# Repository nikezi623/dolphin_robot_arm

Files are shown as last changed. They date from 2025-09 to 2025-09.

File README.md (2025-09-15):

# 🐬 Dolphin Robot Arm

> 基于 STM32F103C8T6 + PS2 手柄的 3 自由度桌面海豚机械臂（包含 SW 模型） 

---

## 📷 项目预览

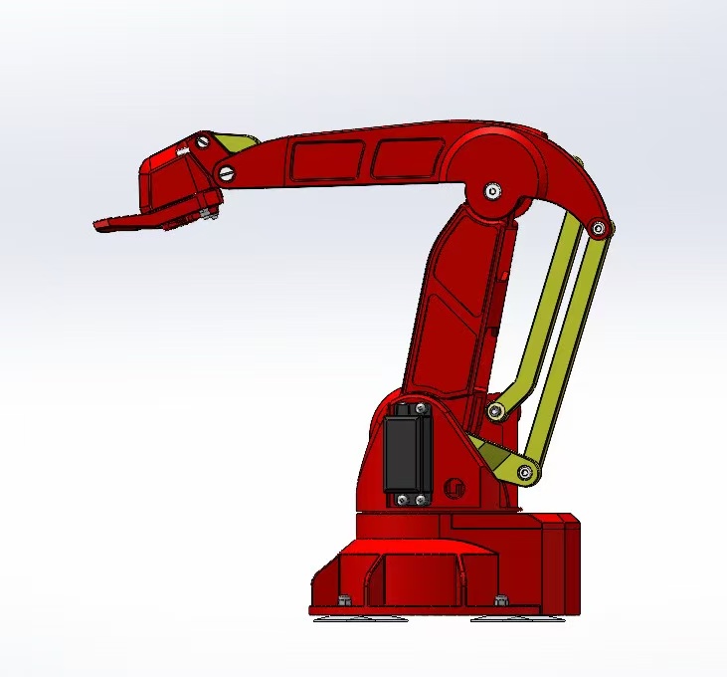
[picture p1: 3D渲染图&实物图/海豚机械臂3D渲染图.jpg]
3D渲染图
<br>
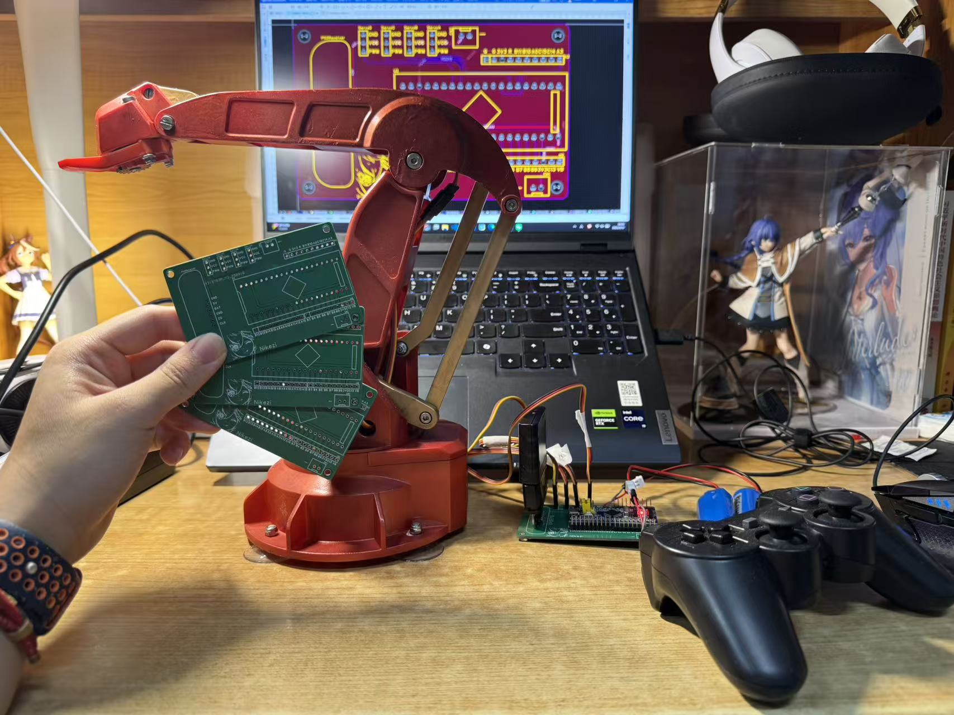
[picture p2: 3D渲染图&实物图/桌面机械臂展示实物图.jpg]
3D渲染图
<br>

[🎥 点击观看演示视频](https://www.bilibili.com/video/BV1tHa8zaEXb/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)

---

## 💻 装配视频<br>
### 视频教程需要付费，作者本人也是跟着视频教程学习的，如无学习建模需求，建议对照本项目的装配体文件自行装配<br>
[🎥 点击跳转装配教程](https://www.bilibili.com/cheese/play/ep34546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)

---

## 原理图<br>
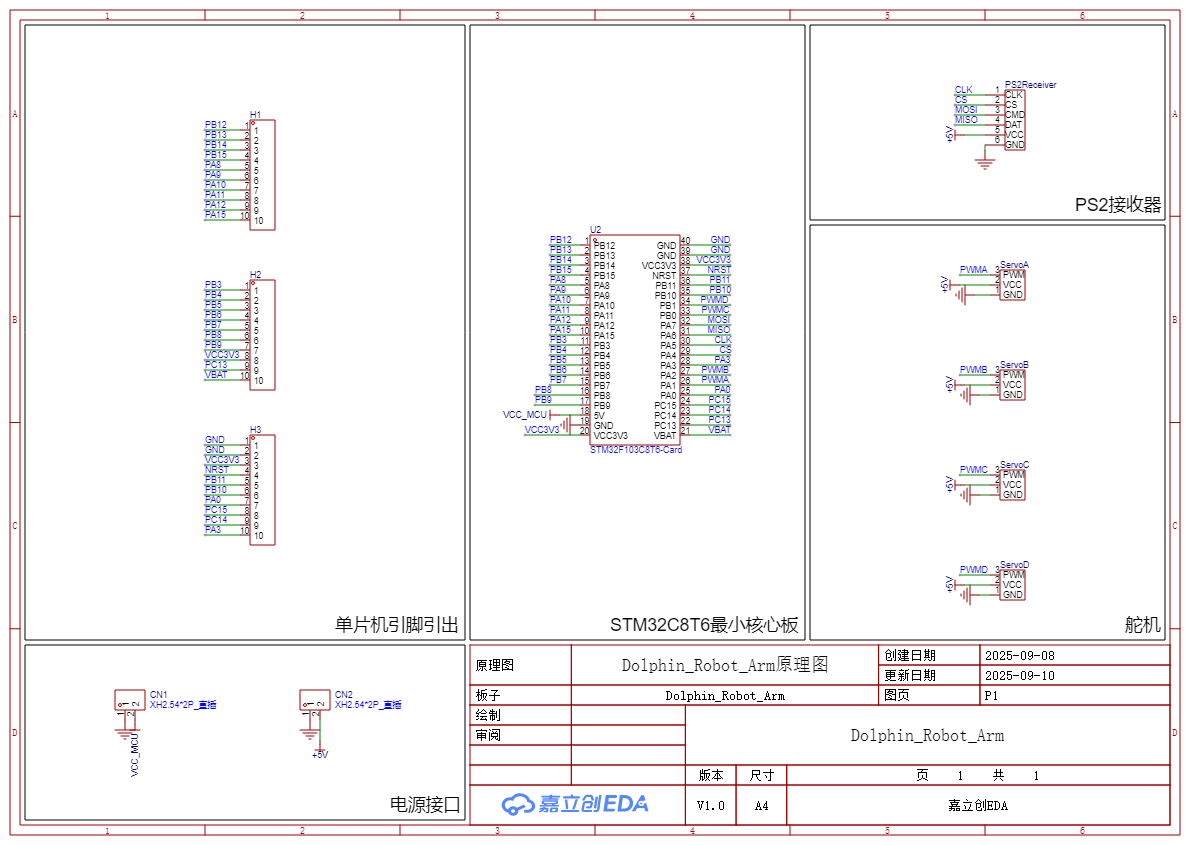
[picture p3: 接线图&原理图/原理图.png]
接线图


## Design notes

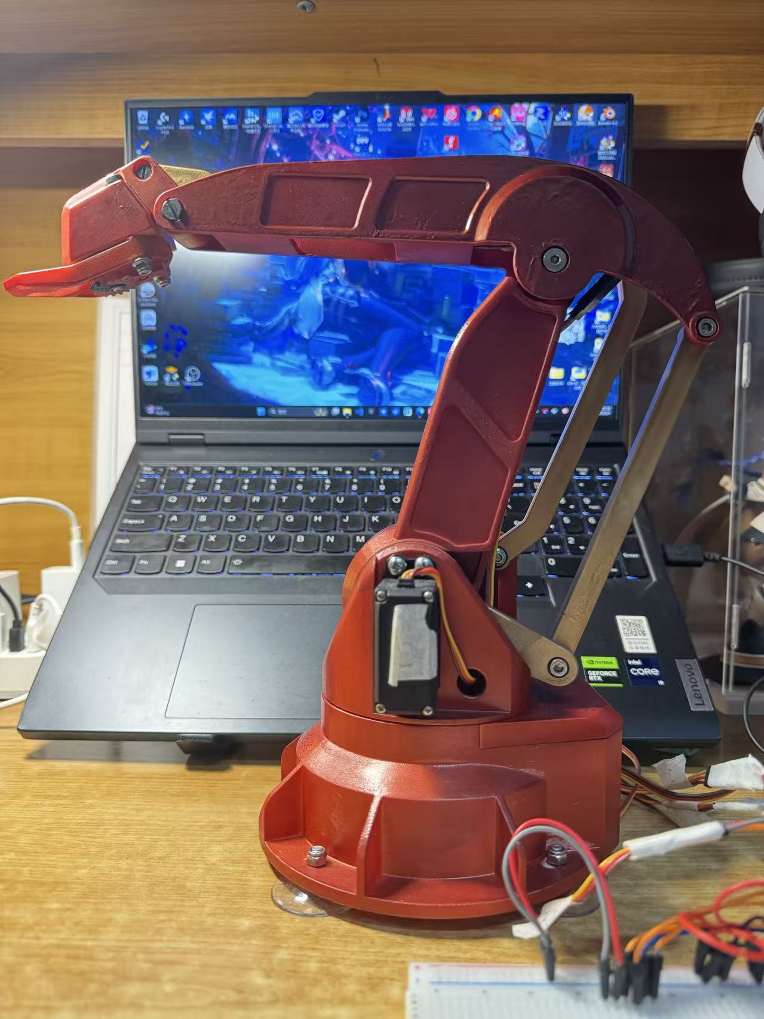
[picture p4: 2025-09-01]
3D渲染图&实物图/海豚机械臂实物图.jpg

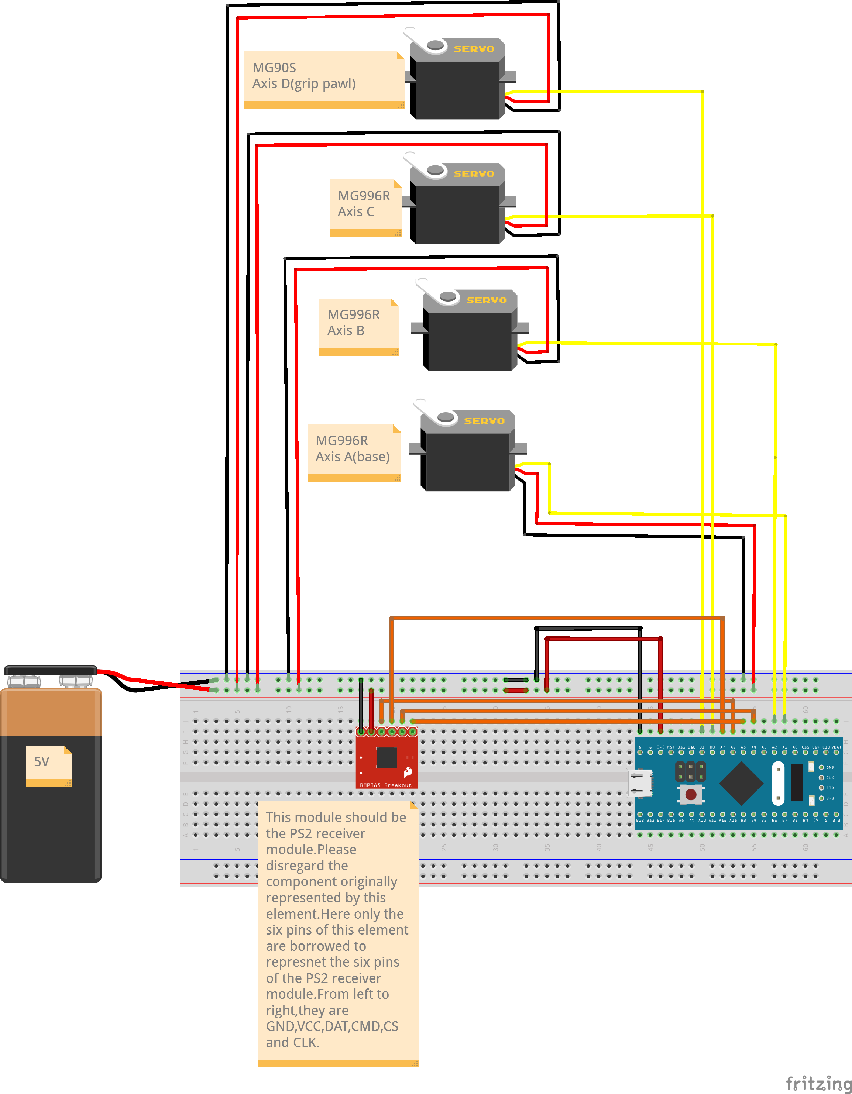
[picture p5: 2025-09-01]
接线图&原理图/接线图-generate_by_fritzing.png

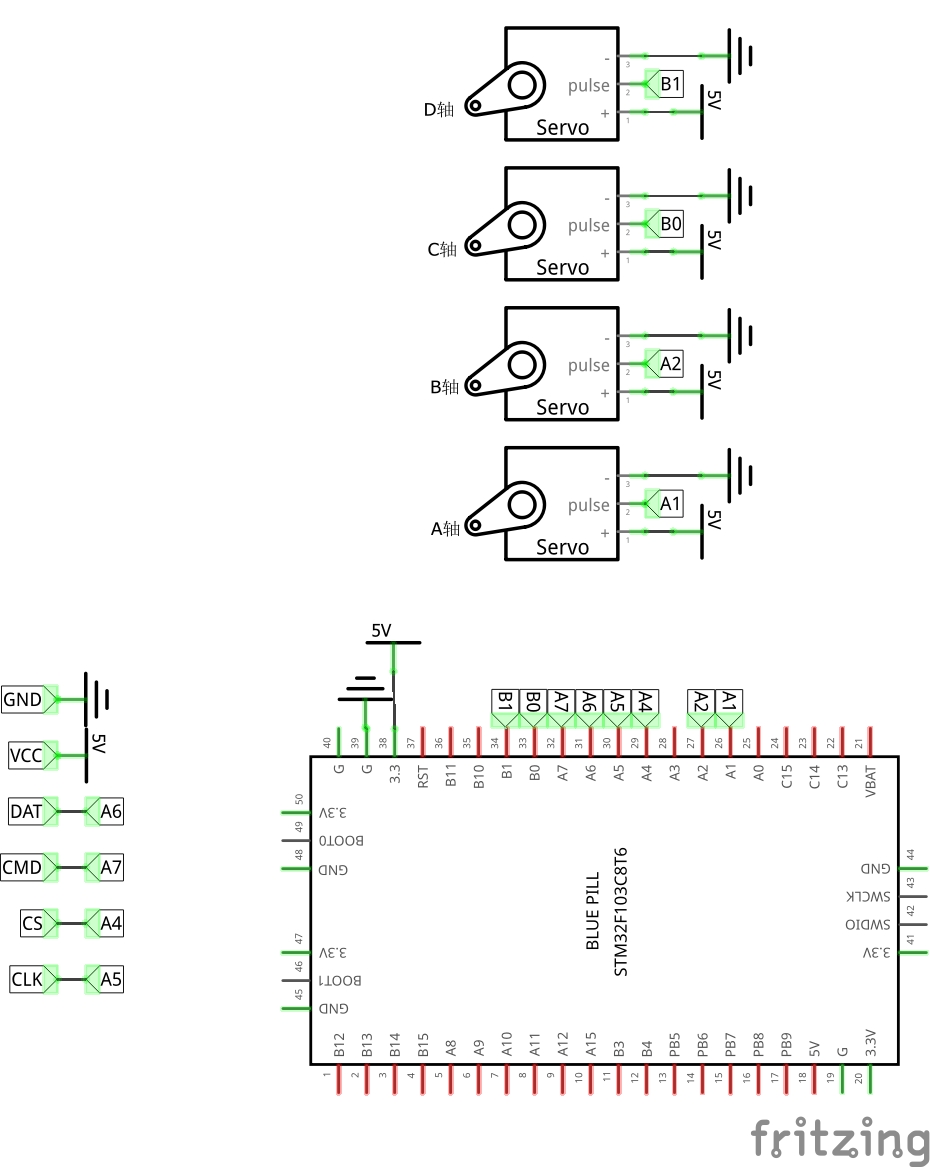
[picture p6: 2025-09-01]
接线图&原理图/原理图-generate_by_fritzing.jpg

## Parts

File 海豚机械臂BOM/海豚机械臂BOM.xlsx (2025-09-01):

海豚机械臂配件表
序号 | 名称 | 链接 | 备注 | 单价 | 数量 | 小计
1 | 标准舵机 | https://detail.tmall.com/item.htm?id=587390473616&_u=lktr7u1ac75&skuId=4166432811194 | MG996 180度 | ￥25.80 | 3 | ￥77.40
2 | 舵机MG90s | https://detail.tmall.com/item.htm?id=587206744069&spm=a1z09.2.0.0.199e2e8d0tGDsQ&_u=lktr7u14a1d | 模拟MG90S 90-180度其他舵机不保证尺寸相同 | ￥16.21 | 1 | ￥16.21
3 | M10×50螺丝 | 8.8级高强度镀锌杯头内六角螺丝钉圆柱头内六角螺栓M4M5M6M8M10-tmall.com天猫 (https://detail.tmall.com/item.htm?id=524283882418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) |  | ￥0.88 | 1 | ￥0.88
4 | M10防松螺母 | 防松自锁螺母 尼龙锁紧防滑六角螺母M2M2.5M3M4M5M6M8M10M12M16-tmall.com天猫 (https://detail.tmall.com/item.htm?id=521350976702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) |  | ￥0.34 | 1 | ￥0.34
5 | M3×12轴肩螺丝 | https://detail.tmall.com/item.htm?id=598344499244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 |  | ￥0.78 | 5 | ￥3.92
6 | M4×20轴肩螺丝 |  |  | ￥0.96 | 1 | ￥0.96
7 | M4×30轴肩螺丝 |  |  | ￥1.12 | 1 | ￥1.12
8 | M3×30轴肩螺丝 |  |  | ￥1.04 | 2 | ￥2.08
9 | M3×12圆柱头螺丝 | 304不锈钢内六角螺丝圆柱头螺钉杯头螺栓加长螺丝钉M3M4M5M6M8M10-tmall.com天猫 (https://detail.tmall.com/item.htm?id=521224502349&spm=a1z09.2.0.0.96a72e8diRnmRM&_u=mktr7u1cfe6) |  | ￥0.06 | 8 | ￥0.48
10 | M3×12自攻螺丝 | https://detail.tmall.com/item.htm?id=524832331089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 |  | ￥0.05 | 8 | ￥0.40
11 | M3×12一字轴肩螺丝 | https://item.taobao.com/item.htm?spm=a1z09.2.0.0.1c752e8dbUoQ1j&id=638005861409&_u=lktr7u1ee1b |  | ￥2.00 | 1 | ￥2.00
12 | M4×25一字轴肩螺丝 |  |  | ￥3.00 | 1 | ￥3.00
13 | M3防滑螺母 | https://detail.tmall.com/item.htm?id=521249356321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 |  | ￥0.09 | 8 | ￥0.72
14 | M3防滑螺母 平底 | 304不锈钢带垫法兰尼龙防松六角螺母/镀锌防滑锁紧螺帽M4M5M6-M10-tmall.com天猫 (https://detail.tmall.com/item.htm?id=521249484210&_u=mktr7u1899c&skuId=3105814838354) |  | ￥0.36 | 4 | ￥1.44
15 | M4防滑螺母 | https://detail.tmall.com/item.htm?id=521249356321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 |  | ￥0.10 | 3 | ￥0.30
16 | m10螺母 | https://detail.tmall.com/item.htm?_u=ektr7u13e0a&id=521159666324 |  | ￥0.20 | 1 | ￥0.20
17 | 轴承619-5 | https://detail.tmall.com/item.htm?id=665677732947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 | 695ZZ | ￥0.55 | 2 | ￥1.10
18 | 轴承61900 | https://detail.tmall.com/item.htm?id=558028332089&_u=lktr7u1a4e0&skuId=3466348596124 | 61900 | ￥0.98 | 1 | ￥0.98
19 | 轴承61809 | https://detail.tmall.com/item.htm?id=558165998149&_u=lktr7u1a06e&skuId=3632300271694 | 61809 | ￥5.20 | 1 | ￥5.20
20 | 易格斯轴承GFM-04050-04 | https://item.taobao.com/item.htm?spm=a1z0d.7625083.1998302264.6.5c5f4e69vvaJRu&id=577055358668 | GFM-04050-04 | ￥3.80 | 12 | ￥45.60
21 | 易格斯轴承GFM-0506-05 | https://item.taobao.com/item.htm?spm=a1z0d.7625083.1998302264.6.5c5f4e69vvaJRu&id=577055358668 | GFM-0506-05 | ￥3.30 | 6 | ￥19.80
22 | 同步带 | https://item.taobao.com/item.htm?spm=a1z0d.7625083.1998302264.6.5c5f4e691gr2Wm&id=609516900382 | STS 264-S3M-6mm宽带宽（mm）：其他 | ￥5.50 | 1 | ￥5.50
23 | 螺丝刀 | https://item.taobao.com/item.htm?id=570916649272&_u=t2dmg8j26111 | 黑批十字3.0 | ￥2.50 | 1 | ￥2.50
24 | 六角匙 | https://detail.tmall.com/item.htm?id=17416455079&spm=a1z09.2.0.0.65382e8d3xBFaW&_u=ektr7u13a87 | CRV平头发黑8.0mm/4支 | ￥1.35 | 1 | ￥1.35
25 | 舵机延长线 | https://item.taobao.com/item.htm?spm=a1z09.2.0.0.1fed2e8dtjAAq1&id=551978474972&_u=ektr7u1ed2e | 60芯 并线棕红橙 飞机种类：200mm 2根 | ￥1.60 | 2 | ￥3.20
26 | 舵机延长线 | https://item.taobao.com/item.htm?spm=a1z0d.7625083.1998302264.6.5c5f4e690OZdu0&id=551978474972 | 60芯 并线棕红橙 飞机种类：500mm 1根 | ￥2.20 | 1 | ￥2.20
27 | 磁铁 | https://item.taobao.com/item.htm?spm=a1z09.2.0.0.66fb2e8d0Q9oc4&id=567498805873&_u=ektr7u1df2d | 直径3mm、厚度4mm | ￥0.21 | 8 | ￥1.68
28 | 吸盘 | https://item.taobao.com/item.htm?spm=a1z09.2.0.0.7e092e8dz8SOxL&id=531984516081&_u=ektr7u16d04 | 3.2cm螺杆M4吸盘配螺母3个 | ￥1.95 | 4 | ￥5.85
 |  |  |  |  | 总计： | ￥206.41

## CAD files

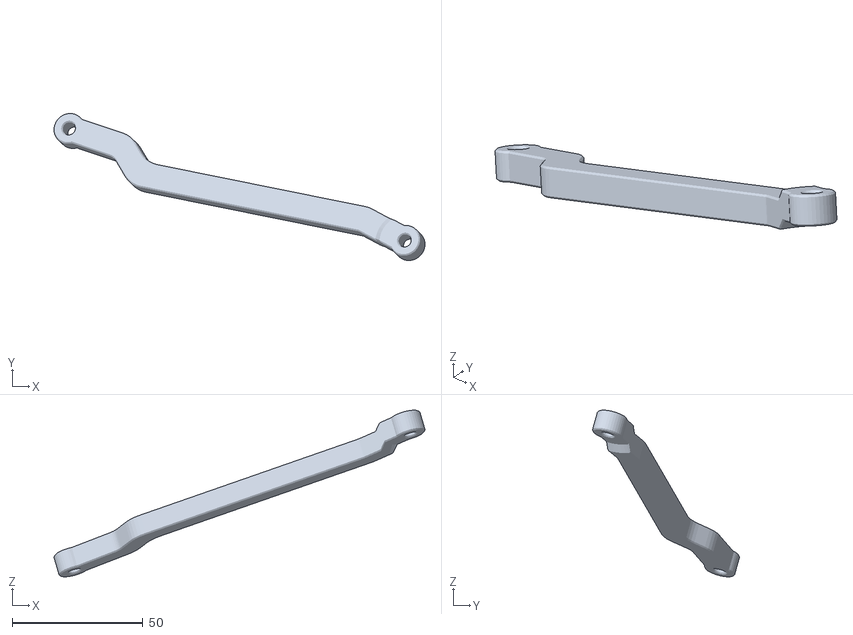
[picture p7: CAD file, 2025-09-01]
海豚机械臂STL文件/BD连杆-1.STL
141.8 x 56.2 x 63.7

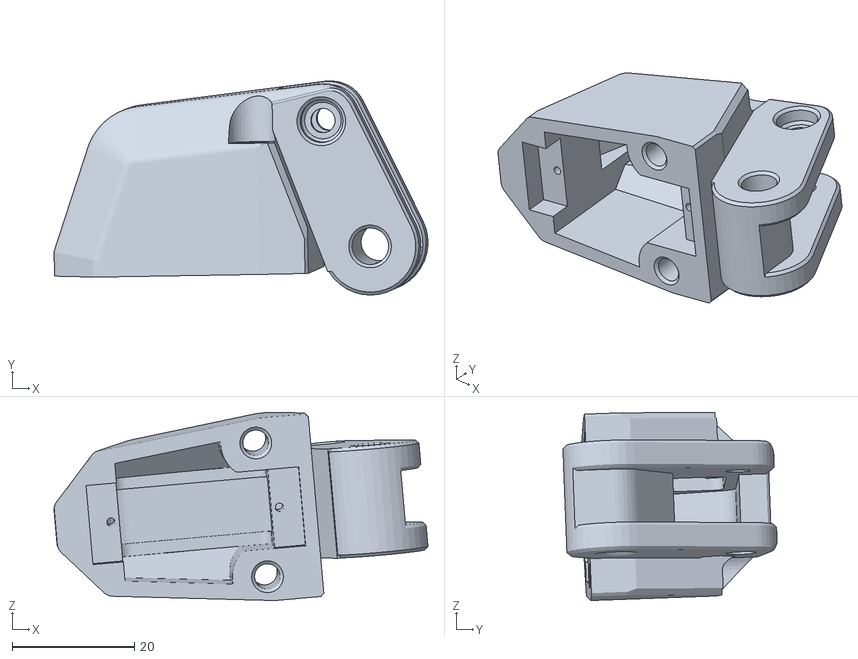
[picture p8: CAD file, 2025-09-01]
海豚机械臂STL文件/夹爪支撑.STL
61.3 x 35.1 x 30.8

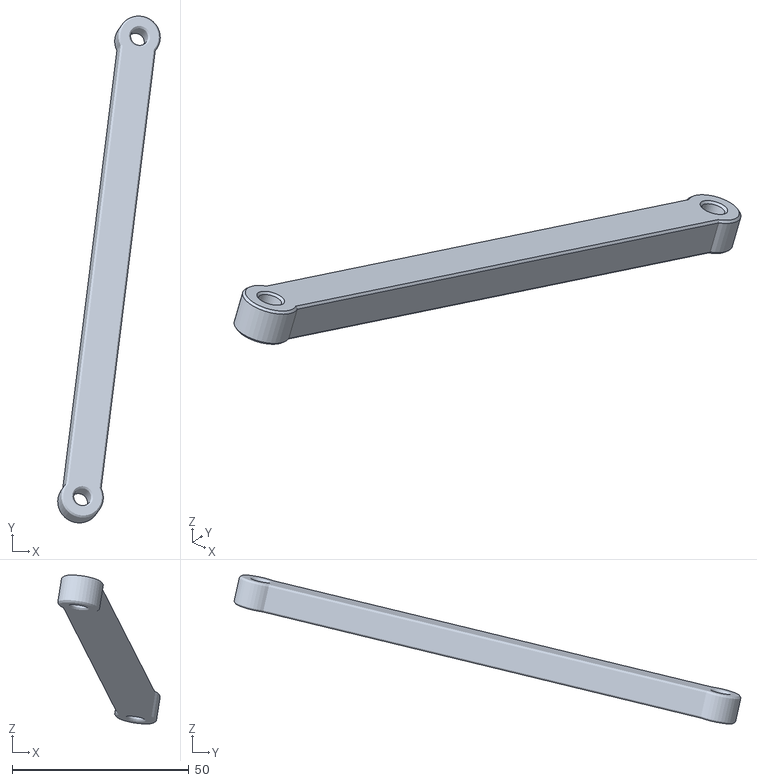
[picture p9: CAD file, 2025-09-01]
海豚机械臂STL文件/CD连杆-2.STL
29.0 x 143.5 x 42.2

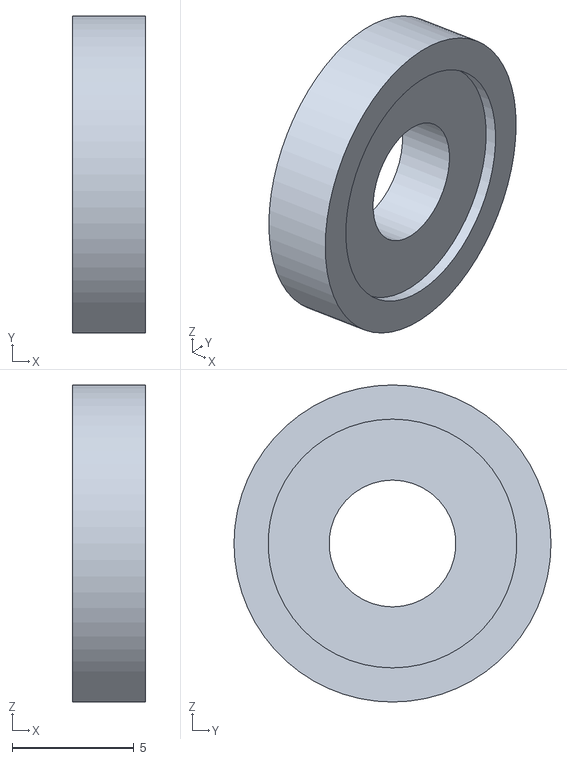
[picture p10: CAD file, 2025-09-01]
海豚机械臂STL文件/BC轴压块.STL
3.00 x 13.0 x 13.0

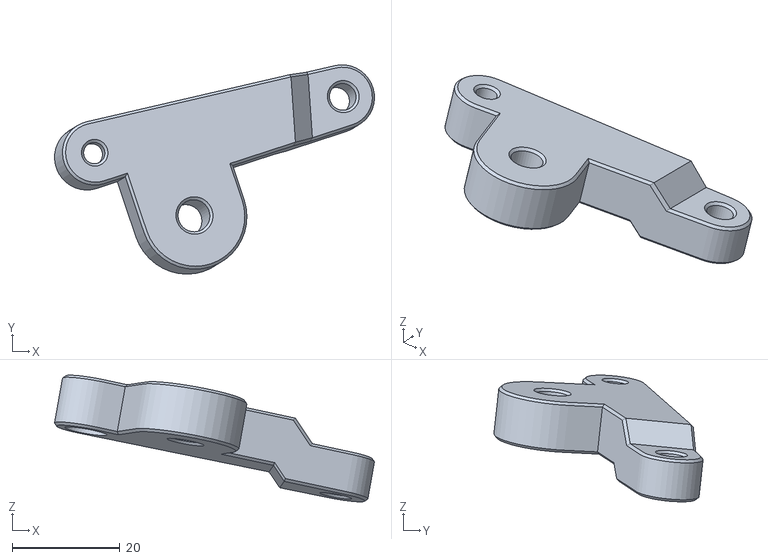
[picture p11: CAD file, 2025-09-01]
海豚机械臂STL文件/三角形连杆.STL
59.5 x 38.9 x 23.6

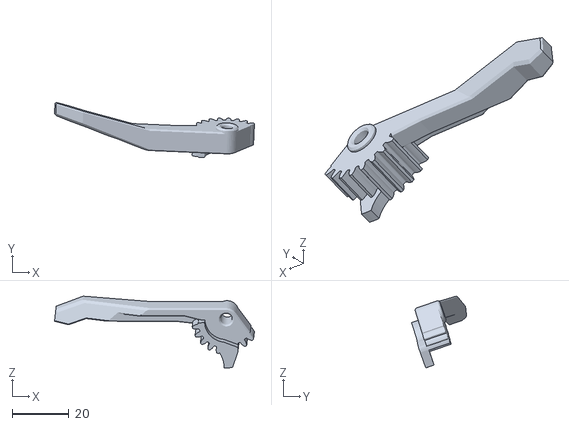
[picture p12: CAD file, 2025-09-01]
海豚机械臂STL文件/上手指.STL
70.3 x 19.4 x 25.2

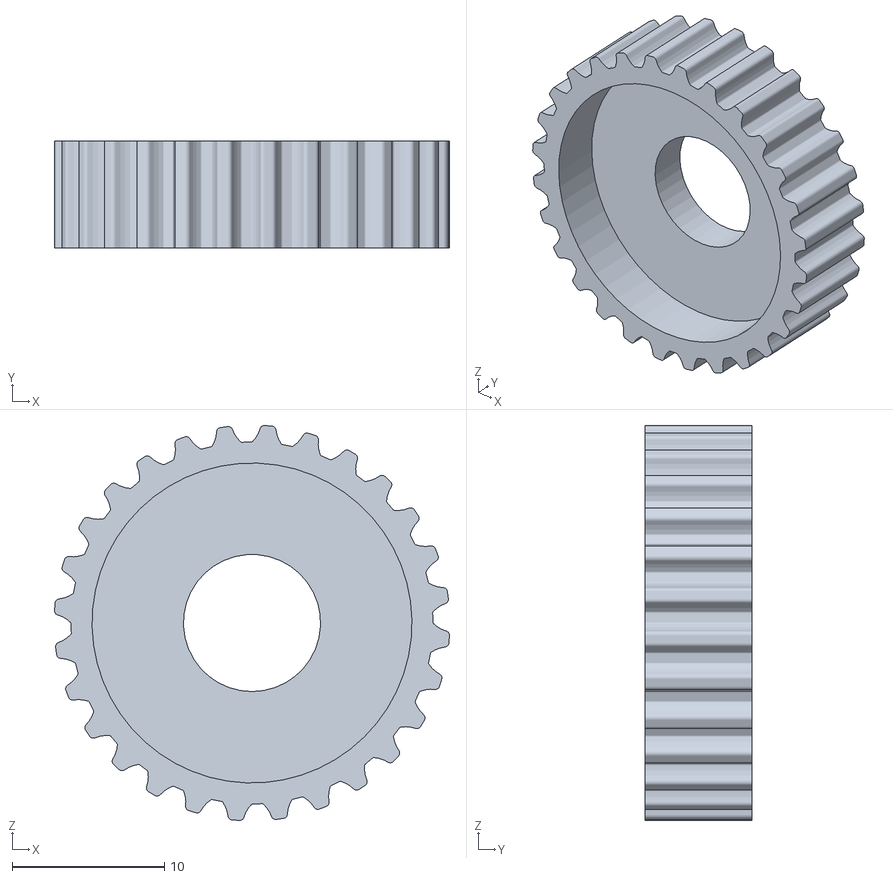
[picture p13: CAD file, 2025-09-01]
海豚机械臂STL文件/旋转底座小同步带轮.STL
25.9 x 7.00 x 25.9

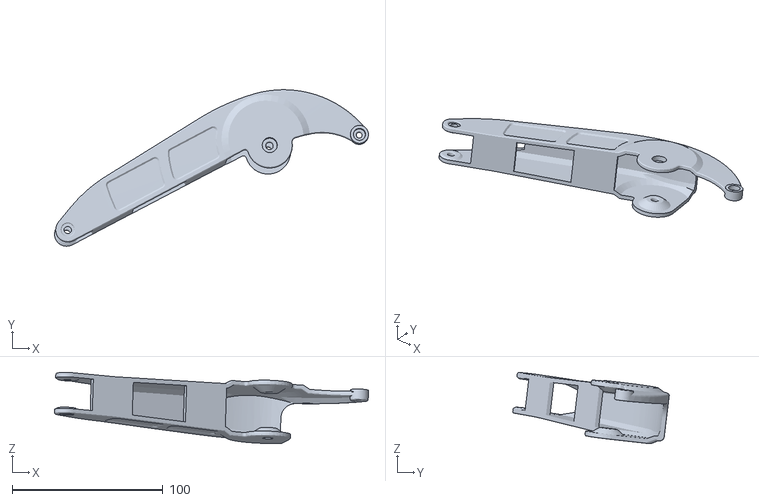
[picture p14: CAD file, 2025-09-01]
海豚机械臂STL文件/CD连杆-1.STL
208.0 x 103.7 x 47.1

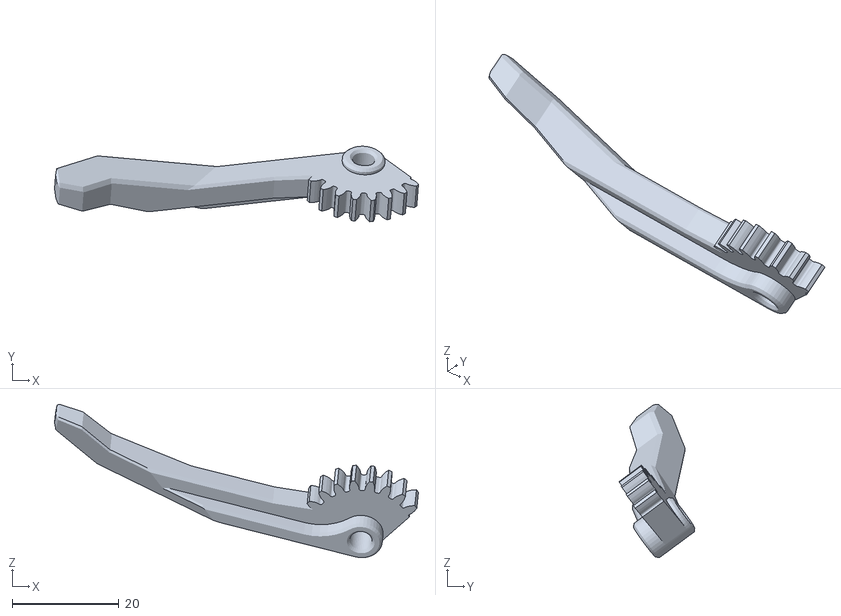
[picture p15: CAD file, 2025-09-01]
海豚机械臂STL文件/下手指.STL
68.1 x 14.1 x 28.7

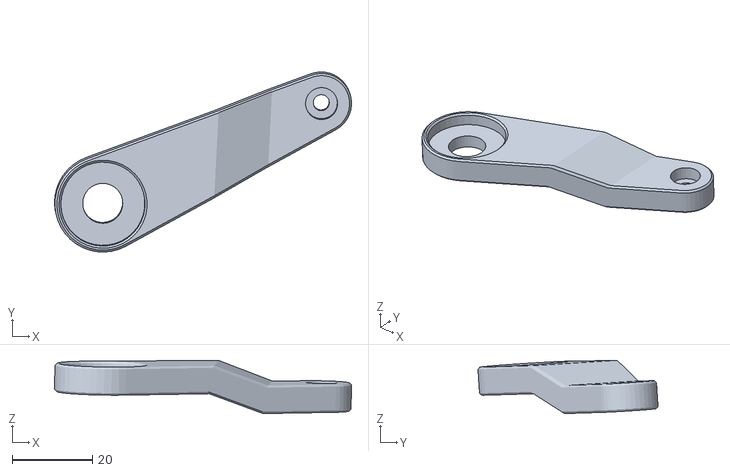
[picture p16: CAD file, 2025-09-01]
海豚机械臂STL文件/CD连杆-3.STL
74.1 x 45.0 x 13.3

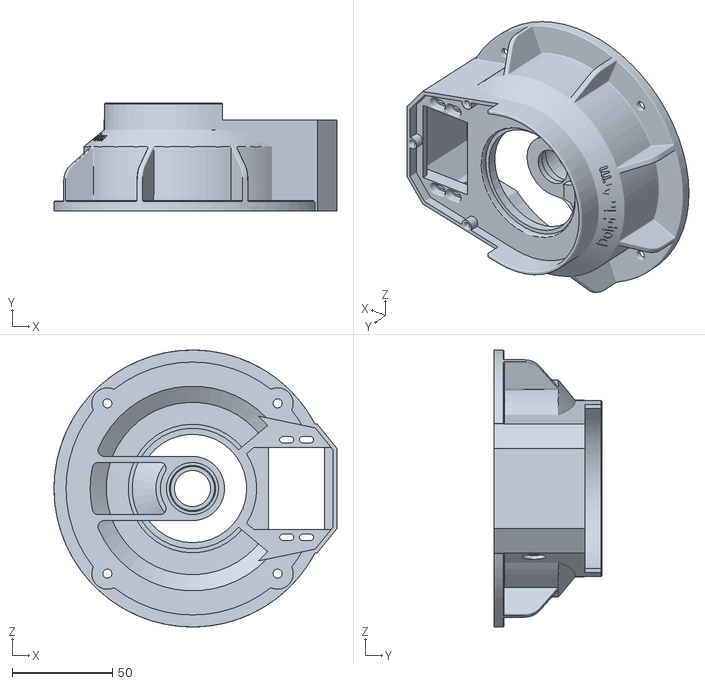
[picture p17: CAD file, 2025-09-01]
海豚机械臂STL文件/固定底座.STL
141.0 x 54.0 x 138.0

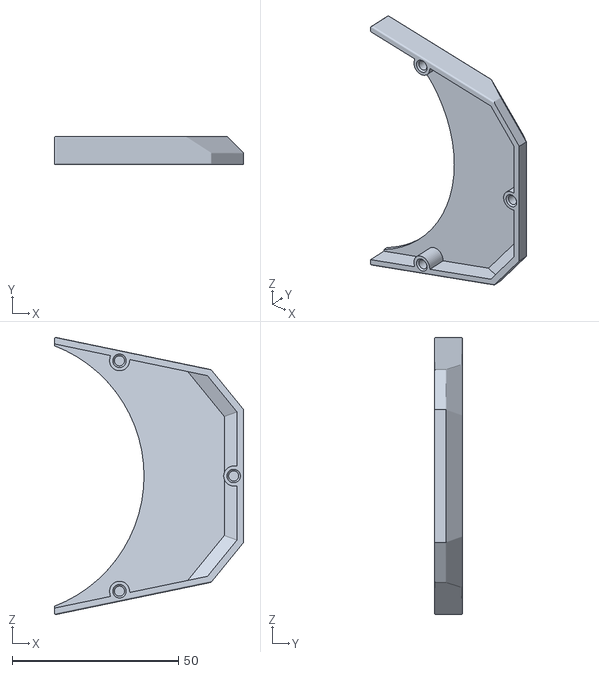
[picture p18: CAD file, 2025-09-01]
海豚机械臂STL文件/固定底座盖子.STL
57.0 x 8.50 x 83.4

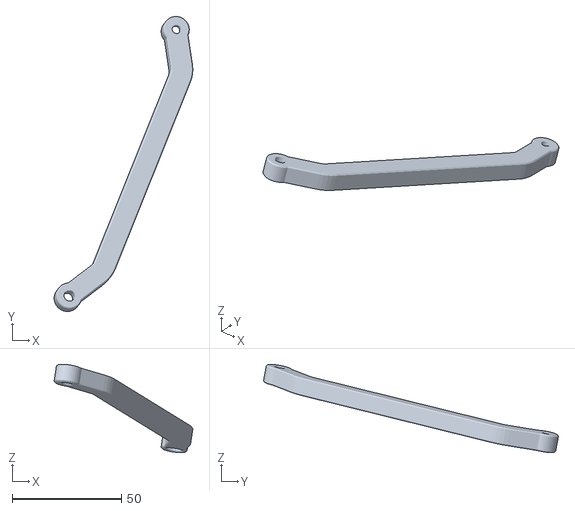
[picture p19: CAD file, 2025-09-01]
海豚机械臂STL文件/BD连杆-2.STL
63.6 x 135.2 x 40.5

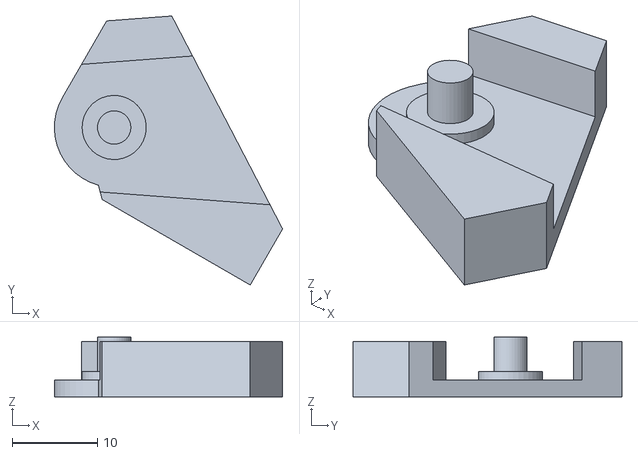
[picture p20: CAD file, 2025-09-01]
海豚机械臂STL文件/C轴舵机舵盘定位块.STL
26.7 x 31.5 x 7.00

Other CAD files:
海豚机械臂STL文件/旋转底座.STL
海豚机械臂STL文件/B轴舵机舵盘定位块.STL
海豚机械臂STL文件/夹爪主动齿.STL
海豚机械臂STL文件/BC连杆.STL
海豚机械臂STL文件/A轴压块.STL
海豚机械臂STL文件/旋转底座大同步带轮.STL

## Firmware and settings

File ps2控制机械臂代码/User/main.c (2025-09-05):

#include "stm32f10x.h"                  // Device header
#include "Delay.h"
#include "MySPI.h"
#include "MyPS2.h"
#include "OLED.h"
#include "Servo.h"
#include "FreeRTOS.h"
#include "task.h"

#define vStartTask_STACK_SIZE 256
#define vStartTask_PRIORITY 1
void vStartTask(void *pvParameters);

int main(void)
{	
	PS2_Init();
	OLED_Init();
	Servo_Init();
	
	Set_A_Angle(A_ANGLE_INIT_VALUE);
	Set_B_Angle(B_ANGLE_INIT_VALUE);
	Set_C_Angle(C_ANGLE_INIT_VALUE);
	Set_D_Angle(D_ANGLE_INIT_VALUE);
	
	Delay_ms(1000);
	
	OLED_ShowString(2, 1, "Lx:000"); OLED_ShowString(2, 8, "Ly:000"); 
	OLED_ShowString(3, 1, "Rx:000"); OLED_ShowString(3, 8, "Ry:000");
	
	xTaskCreate(vStartTask, "vStartTask", vStartTask_STACK_SIZE, NULL, vStartTask_PRIORITY, NULL);
	
	vTaskStartScheduler();
	
	while(1)
	{
		
	}
}

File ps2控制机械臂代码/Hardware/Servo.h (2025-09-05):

#ifndef __Servo_H
#define __Servo_H

#define A_ANGLE_INIT_VALUE 		90
#define B_ANGLE_INIT_VALUE 		0
#define C_ANGLE_INIT_VALUE 		180
#define D_ANGLE_INIT_VALUE 		65

#define A_ANGLE_MAX 			180
#define A_ANGLE_MIN 			0

#define B_ANGLE_MAX 			85
#define B_ANGLE_MIN 			0

#define C_ANGLE_MAX 			180
#define C_ANGLE_MIN 			90

#define D_ANGLE_MAX 			114
#define D_ANGLE_MIN 			65

void Servo_Init(void);
void Set_A_Angle(float A_Angle);
void Set_B_Angle(float A_Angle);
void Set_C_Angle(float C_Angle);
void Set_D_Angle(float D_Angle);

extern uint8_t Lx, Ly, Rx, Ry;
extern float A_Angle;
extern float B_Angle;
extern float C_Angle;
extern float D_Angle;

#endif

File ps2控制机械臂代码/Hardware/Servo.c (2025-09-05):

#include "stm32f10x.h"                  // Device header
#include "PWM.h"
#include "string.h"
#include "MyPS2.h"
#include "Delay.h"
#include "MyPS2.h"
#include "MySPI.h"
#include "FreeRTOS.h"
#include "task.h"
#include "OLED.h"
#include "Servo.h"

uint8_t Lx, Ly, Rx, Ry;
float A_Angle = A_ANGLE_INIT_VALUE;
float B_Angle = B_ANGLE_INIT_VALUE;
float C_Angle = C_ANGLE_INIT_VALUE;
float D_Angle = D_ANGLE_INIT_VALUE;

void Servo_Init(void)
{
	PWM_Init();
}

void Set_A_Angle(float A_Angle)
{
	PWM_SetCompare2A((A_Angle / 1800 + 0.025) * 20000);
}

void Set_B_Angle(float B_Angle)
{
	PWM_SetCompare2B((B_Angle / 1800 + 0.025) * 20000);
}

void Set_C_Angle(float C_Angle)
{
	PWM_SetCompare3C((C_Angle / 1800 + 0.025) * 20000);
}

void Set_D_Angle(float D_Angle)
{
	PWM_SetCompare4D((D_Angle / 1800 + 0.025) * 20000);
}

void A_Angle_Plus(void *pvParameters)
{
	while (1)
	{
		if (Lx < 0x80)
		{
			if (A_Angle < A_ANGLE_MAX) A_Angle += 0.3;
			if (A_Angle > A_ANGLE_MAX) A_Angle = A_ANGLE_MAX;
			Set_A_Angle(A_Angle);
		}
		vTaskDelay(10);
	}
}

void A_Angle_Minus(void *pvParameters)
{	
	while (1)
	{
		if (Lx > 0x80)
		{
			if (A_Angle > A_ANGLE_MIN) A_Angle -= 0.3;
			if (A_Angle < A_ANGLE_MIN) A_Angle = A_ANGLE_MIN;
			Set_A_Angle(A_Angle);
		}
		vTaskDelay(10);
	}
}

void B_Angle_Plus(void *pvParameters)
{
	while (1)
	{
		if(Rx < 0x80)
		{
			if (B_Angle < B_ANGLE_MAX) B_Angle += 0.2;
			if (B_Angle > B_ANGLE_MAX) B_Angle = B_ANGLE_MAX;
			Set_B_Angle(B_Angle);
		}
		vTaskDelay(10);
	}
}

void B_Angle_Minus(void *pvParameters)
{	
	while (1)
	{
		if (Rx > 0x80)
		{
			if (B_Angle > B_ANGLE_MIN) B_Angle -= 0.2;
			if (B_Angle < B_ANGLE_MIN) B_Angle = B_ANGLE_MIN;
			Set_B_Angle(B_Angle);
		}
		vTaskDelay(10);
	}
}

void C_Angle_Plus(void *pvParameters)
{
	while (1)
	{
		if (Ry < 0x7F)
		{
			if (C_Angle < C_ANGLE_MAX) C_Angle += 0.2;
			if (C_Angle > C_ANGLE_MAX) C_Angle = C_ANGLE_MAX;
			Set_C_Angle(C_Angle);
		}
		vTaskDelay(10);
	}
}

void C_Angle_Minus(void *pvParameters)
{	
	while (1)
	{
		if (Ry > 0x7F)
		{
			if (C_Angle > C_ANGLE_MIN) C_Angle -= 0.2;
			if (C_Angle < C_ANGLE_MIN) C_Angle = C_ANGLE_MIN;
			Set_C_Angle(C_Angle);
		}
		vTaskDelay(10);
	}
}

void D_Angle_Plus(void *pvParameters)
{
	while (1)
	{
		if (Get_Key() == L1)
		{
			if (D_Angle < D_ANGLE_MAX) D_Angle += 0.2;
			if (D_Angle > D_ANGLE_MAX) D_Angle = D_ANGLE_MAX;
			Set_D_Angle(D_Angle);
		}
		vTaskDelay(2);
	}
}

void D_Angle_Minus(void *pvParameters)
{	
	while (1)
	{
		if (Get_Key() == R1)
		{
			if (D_Angle > D_ANGLE_MIN) D_Angle -= 0.2;
			if (D_Angle < D_ANGLE_MIN) D_Angle = D_ANGLE_MIN;
			Set_D_Angle(D_Angle);
		}
		vTaskDelay(2);
	}
}

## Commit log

2025-09-01 Rename 原理图（generate by fritzing）.jpg to 原理图-generate by fritzing.jpg
    去除括号
2025-09-01 Rename 接线图（generate by fritzing）.png to 接线图-generate by fritzing.png
    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
2025-09-01 Rename 原理图-generate by fritzing.jpg to 原理图-generate_by_fritzing.jpg
    去除空格
2025-09-01 Rename 接线图-generate by fritzing.png to 接线图-generate_by_fritzing.png
    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
2025-09-01 Update README.md
    添加接线图和原理图
2025-09-05 Create 机械臂控制代码_FreeRTOS版
    使用了FreeRTOS优化了机械臂的控制逻辑，实现了机械臂的连续运动以及同时多向运动
2025-09-05 Add files via upload
    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
2025-09-10 Update README.md
    更新了原理图
